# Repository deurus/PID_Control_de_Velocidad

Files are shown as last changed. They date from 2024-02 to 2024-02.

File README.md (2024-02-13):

# CONTROL DE VELOCIDAD DE UN MOTOR

En esta entrada, exploraremos una implementación básica y fácil de entender del control de velocidad de un motor usando Arduino. Aunque es un ejemplo simple, sirve como un excelente punto de partida hacia implementaciones más avanzadas y profesionales. Para este proyecto, he utilizado un conocido motorreductor junto con un encoder infrarrojo, elementos comunes en la construcción de maquetas de vehículos a pequeña escala.

<h2>Esquema de conexiones</h2>
<p align="center">
  conexiones
  <br>
  conexiones
</p>

<h2>Esquema de control</h2>
<p align="center">
  conexiones
</p>

En el esquema de control hay dos componentes principales identificados:

<b>Encoder (SC-1)</b>: Este dispositivo se utiliza para capturar la velocidad de rotación del eje del motor y convertirla en señales eléctricas. Cada vez que el eje gira, el encoder genera pulsos que se pueden contar para determinar la velocidad de rotación.

<b>Motor de corriente continua</b>: Representado en la parte inferior de la imagen. El motor es la parte del sistema que realiza el trabajo mecánico y cuya velocidad se desea controlar. La señal de control proveniente del controlador PID modula la energía suministrada al motor para mantener la velocidad deseada.

El motor se pone en marcha y su velocidad de rotación es capturada por el encoder. Esta velocidad es enviada al controlador PID, que compara la velocidad real (variable de proceso o PV) con la velocidad deseada (punto de consigna o SP). Si hay una diferencia entre la velocidad real y la deseada, el controlador PID calcula una señal de control (OP) adecuada para ajustar la potencia del motor y corregir el error. Esta señal de control ajusta la velocidad del motor, ya sea aumentándola o disminuyéndola para que coincida con el. Este es un proceso continuo y dinámico donde el controlador PID constantemente ajusta la señal de control en respuesta a las variaciones en la velocidad del motor para mantener la velocidad estable. En resumen, este esquema representa un sistema de control en lazo cerrado para mantener una velocidad constante en un motor de corriente continua, utilizando para ello un controlador PID que procesa la información del encoder y ajusta la señal de potencia al motor.

<h2>Vídeos</h2>
 - Ajuste del filtro EMA: https://www.youtube.com/watch?v=WHUFHLzo4Hg <br>
 - Prueba de sintonías: https://www.youtube.com/watch?v=KG6Sc1nF7P8 <br>
 <br>
Tenéis más información en la entrada del blog: https://garikoitz.info/blog/2024/01/sintonizar-pid-con-arduino-control-de-velocidad-de-un-motor/

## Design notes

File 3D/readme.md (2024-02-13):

# Modelo 3D

Se ha creado una pequeña base para poder fijar el motor y así poder situarlo correctamente encarado al encoder.

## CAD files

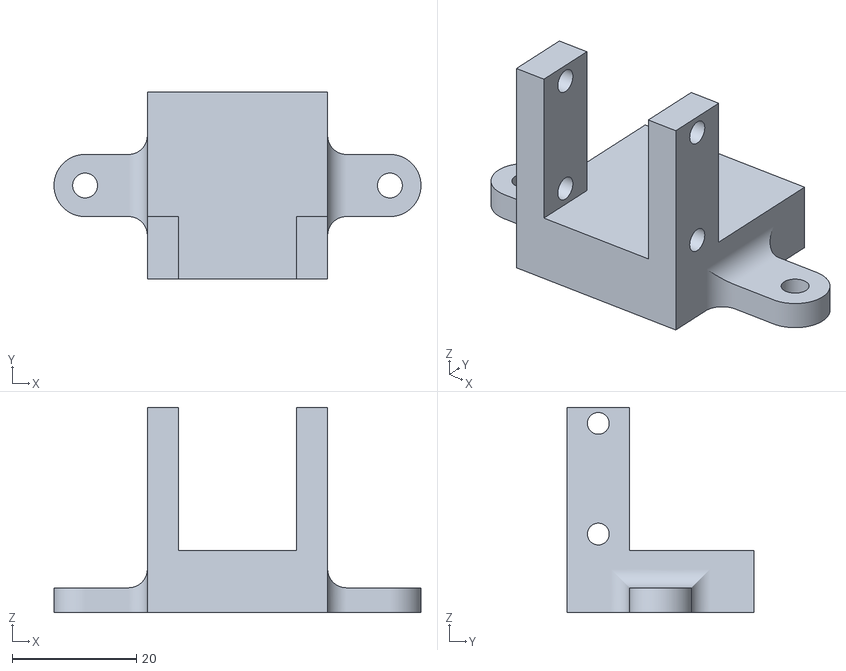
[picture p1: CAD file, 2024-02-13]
3D/Base_MotorCC.stl
59.0 x 30.0 x 33.0

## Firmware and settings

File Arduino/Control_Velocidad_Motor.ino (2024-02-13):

/***************************************************************
* Control de velocidad de Motor CC mediante encoder infrarrojo
* Desarrollado por Garikoitz Martínez [garikoitz.info] [01/2024]
* https://garikoitz.info/blog/?p=2131
***************************************************************/
/***************************************************************
* Librerías
***************************************************************/
#include <PID_v1.h>
/***************************************************************
* Variables
***************************************************************/
int IN2 = 2; // Encoder en pin 2
int IN3 = 5; // Input3 conectada al pin 5
int IN4 = 4; // Input4 conectada al pin 4
int ENB = 3; // ENB conectada al pin 3 de Arduino
const long baud = 9600; // serial baud rate
int Ts = 100; //Sample time in ms
unsigned long previousMillis = 0;
static volatile unsigned long lastTimeDebounce = 0; //Tiempo del rebote
//Motores
float M1_PV = 0.0;
float M1_SP = 0.0;
int M1_OP = 0;
int M1SPMIN = 100;   //en AUTO
int M1SPMAX = 350; //con este motor max 400 RPMs a 7V
int M1OPMIN = 0;
int M1OPMAX = 100; //5% = 100pwm -> se empieza a mover a partir de 100pwm cuando vienes de motor parado
//Encoder
double RPMs = 0.0;
double RPMsFilter = RPMs;
double alpha = 0.1; //Filtro EMA 0.2-0.4 con Ts=1000ms y 0.1-0.2 con Ts=100ms
volatile int frecuencia = 0;//numero de pulsos leidos por Arduino
int nRanuras = 20; //numero de ranuras del disco
// global variables
const char sp = ' ';           
const char nl = '\n';
boolean newData = false; 
char Buffer[64]; 
int buffer_index = 0; 
String cmd;  
float val;
/***************************************************************
* Sintonías calculadas (Lazo abierto --> Kc=1.125 T0=.4s Tp=.3s)
***************************************************************/
//double Kc=0.67, Ki=1.76, Kd=0.00;   //CC-25
//double Kc=0.40, Ki=0.87, Kd=0.00;   //CC-10
//double Kc=0.08, Ki=0.27, Kd=0.00;   //LAMBDA Tf=3s
//---------------------------------------------------------------
double SetpointM1, InputM1, OutputM1;
double KcM1=0.67, KiM1=1.76, KdM1=0.0; 
PID PIDM1(&InputM1, &OutputM1, &SetpointM1, KcM1, KiM1, KdM1, P_ON_E, DIRECT);    //PI-D
//PID PIDT1(&InputT1, &OutputT1, &SetpointT1, KcT1, KiT1, KdT1, P_ON_M, DIRECT);  //I-PD
/***************************************************************
* SETUP
***************************************************************/
void setup()
{
  pinMode (ENB, OUTPUT);
  pinMode (IN3, OUTPUT);
  pinMode (IN4, OUTPUT);
  //Preparamos la salida para que el motor gire en un sentido
  digitalWrite (IN3, LOW);
  digitalWrite (IN4, HIGH);
  while (!Serial) {
    // wait for serial port to connect.
  }
  Serial.begin(baud);
  //Serial.flush();
  attachInterrupt(digitalPinToInterrupt(IN2),interrupcion0,RISING); //Lectura de los pulsos Encoder
  //
  previousMillis=0;
  PIDM1.SetOutputLimits(0, 255);
  PIDM1.SetMode(MANUAL);
  if (Ts < 100){
    PIDM1.SetSampleTime(Ts);
  }
}
/***************************************************************
* BUCLE PRINCIPAL
***************************************************************/
void loop()
{
  if (millis() - previousMillis > Ts)
  {
    //Lectura del encoder
    RPMs = (frecuencia * 60000.0)/((millis()-previousMillis)*nRanuras);
    RPMsFilter = alpha*RPMs+(1.0-alpha)*RPMsFilter; //Filtro EMA
    M1_PV = RPMsFilter;
    previousMillis = millis();
    frecuencia = 0;
    //Funciones Lectura/Escritura Serial
    LeoCMD();
    ProcesoCMD();
    EjecutoCMD();
    //PID (Parámetros vía serial cmds)
    if (PIDM1.GetMode() == 1){//AUTO
        InputM1 = M1_PV;
        SetpointM1 = M1_SP;
        PIDM1.Compute();
        M1_OP = map(OutputM1, 0, 255, 0, 100); //PWM -> %
        analogWrite(ENB,OutputM1);
     }else if (PIDM1.GetMode() == 0) {//MANUAL
		/*>>INICIALIZACIÓN<< -> para evitar problemas al pasar de MANUAL a AUTO
		(1) --> PV Tracking -> igualamos SP a PV
		(2) --> Calculamos la salida de control para que 'inicialice' correctamente el PID sin provocar saltos bruscos al pasar de Manual a Auto.
		*/
		M1_SP = M1_PV; //(1)
        OutputM1 = map(M1_OP, 0, 100, 0, 255); //(2)
     }
     //Para Arduino COM Plotter
     Serial.print("#");        //Char inicio
     Serial.print(M1_SP,0);    //
     Serial.write(" ");        //separador
     Serial.print(M1_PV,0);    //
     Serial.write(" ");        //separador
     Serial.print(M1_OP);      //
     Serial.println();
    //
  } //millis
} //loop
/***************************************************************
* FUNCIONES
***************************************************************/
void interrupcion0()
{
  if(digitalRead(IN2) && (micros()-lastTimeDebounce >= 500))
  {
    lastTimeDebounce = micros();
    frecuencia++;  
  }  
}
//No hace falta tocar
void LeoCMD() {
  while (Serial && (Serial.available() > 0) && (newData == false)) {
    int byte = Serial.read();
    if ((byte != '\r') && (byte != nl) && (buffer_index < 64)) {
      Buffer[buffer_index] = byte;
      buffer_index++;
    }
    else {
      newData = true;
    }
  }   
}
//No hace falta tocar
void ProcesoCMD(void) {
  if (newData) {
    String read_ = String(Buffer);
    // separate command from associated data
    int idx = read_.indexOf(sp);
    cmd = read_.substring(0, idx);
    cmd.trim();
    cmd.toUpperCase();
    // extract data. toFloat() returns 0 on error
    String data = read_.substring(idx + 1);
    data.trim();
    val = data.toFloat();
    // reset parameter for next command
    memset(Buffer, 0, sizeof(Buffer));
    buffer_index = 0;
    newData = false;
  }
}
//Aquí personaliza tus comandos
void EjecutoCMD(void) {
  if (cmd == "M1A") {
    PIDM1.SetMode(AUTOMATIC);
  }
  else if (cmd == "M1M") {
    PIDM1.SetMode(MANUAL);
  }
  else if (cmd == "M1SP") {
    if (PIDM1.GetMode() == 1){
      if (val > M1SPMAX){
        val = M1SPMAX;
      }
    if (val < M1SPMIN){
        val = M1SPMIN;
      }
    M1_SP = val;
    }
  }
  else if (cmd == "M1OP") {
    if (PIDM1.GetMode() == 0){
      if (val > M1OPMAX){
        val = M1OPMAX;
      }
      if (val < M1OPMIN){
        val = M1OPMIN;
      }
      M1_OP = val;
      //map(value, fromLow, fromHigh, toLow, toHigh)
      val = map(val, 0, 100, 0, 255);
      analogWrite(ENB,val);
    }
  }
  else if (cmd == "M1KC") {
    PIDM1.SetTunings(val,KiM1,KdM1);
  }
  else if (cmd == "M1KI") {
    PIDM1.SetTunings(KcM1,val,KdM1);
  }
  else if (cmd == "M1KD") {
    PIDM1.SetTunings(KcM1,KiM1,val);
  }
  else if (cmd == "FILTRO") {
    if (val > 1){
        val = 1;
    }
    if (val <= 0){
        val = 0.01;
    }
    alpha = val;
  }
  Serial.flush();
  cmd = "";
}
